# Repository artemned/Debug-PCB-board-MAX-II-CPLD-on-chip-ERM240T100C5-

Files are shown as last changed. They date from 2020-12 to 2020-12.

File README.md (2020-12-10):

# Debug-PCB-board-MAX-II-CPLD-on-chip-ERM240T100C5-
##  Some variation board models   
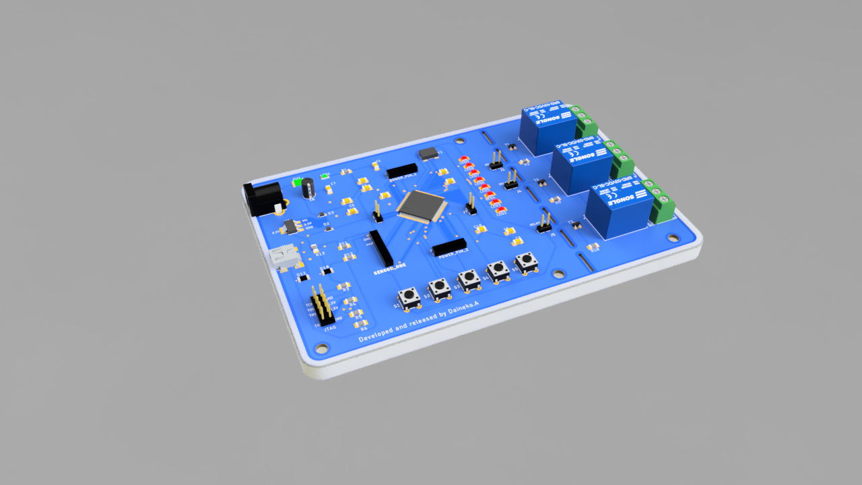
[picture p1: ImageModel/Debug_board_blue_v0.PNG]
 
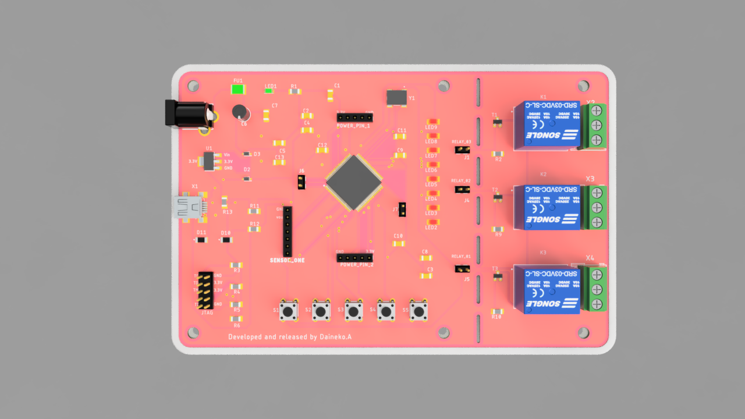
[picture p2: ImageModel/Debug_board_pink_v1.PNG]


### To create this project I was inspired by the ability to synthesize digital circuits using the Verilog and System Verilog languages.From my own experience, I would like to note that many industrial controllers or programmable relays use “Functional block diagram” semantics as a description of control system algorithms. Naturally, the experience gained with this board can be easily used in industry to obtain reliable, efficient and inexpensive solutions.But and not only in industry.Further in this repository in the Examples package, examples of synthesized circuits will appear. The whole project: entirely built on enthusiasm. Therefore, you can become a co-author and contribute.I am grateful to everyone who has read this far. For questions and suggestions, write to the email address: daineko.a32@mail.ru P.S. All goodness and fresh cookies!

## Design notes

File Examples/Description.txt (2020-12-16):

This is the first synthesis for
of this board, so I created a simple circuit that,
when the button is pressed, toggles the next bit of the LED.

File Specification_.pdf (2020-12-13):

Part | Value | Package | Description
C1 | 0.01uF | C1206 | Capacitor
C2 | 1uF | C1206 | Capacitor
C3 | 0.1uF | C1206 | Capacitor
C4 | 1uF | C1206 | Capacitor
C5 | 1uF | C1206 | Capacitor
C6 | 10uF | E2-5 | Polarized capacitor
C7 | 0.1uF | C1206 | Capacitor
C8 | 0.1uF | C1206 | Capacitor
C9 | 0.1uF | C1206 | Capacitor
C10 | 0.1uF | C1206 | Capacitor
C11 | 0.1uF | C1206 | Capacitor
C12 | 0.1uF | C1206 | Capacitor
C13 | 1uF | C1206 | Capacitor
D2 | BAT60AE6327HTSA1 | SOD2513X110N | BAT60AE6327HTSA1 - RECTIFIER, SCHOTTKY, 3A, 10V, SOD-323
D3 | BAT60AE6327HTSA1 | SOD2513X110N | BAT60AE6327HTSA1 - RECTIFIER, SCHOTTKY, 3A, 10V, SOD-323
D10 | 3.6V | BZV55C3V9TP
D11 | 3.3V | BZV55C3V9TP
FU1 | MF-MSMF110_16-2 | FUSC4632X85N | Fuse, PTC, Resettable, SMD,1812,1.1A,16V
IC2 | EPM240T100C5N | QFP50P1600X1600X120-100N | CPLD Max II EPM240T100C5N, TQFP100 EPM240T100C5N
J1 | | 1X02_LOCK | Standard 2-pin 0.1 header. Use with"
J2 | POWER_JACK | POWER_JACK_PTH | Power Jack Connector
J4 | | 1X02_LOCK | Standard 2-pin 0.1 header.
J5 | | 1X02_LOCK | Standard 2-pin 0.1 header.
J6 | | 1X02_LOCK | Standard 2-pin 0.1 header.
J7 | | 1X02_LOCK | Standard 2-pin 0.1 header.
JTAG | | 2X5_NOSILK | Header 5x2
K1 | SRD-05VDC-SL-C | RELAY_SRD-05VDC-SL-C | 5V Trigger Relay Module For Arduino And Raspberry Pi
K2 | SRD-05VDC-SL-C | RELAY_SRD-05VDC-SL-C | 5V Trigger Relay Module For Arduino And Raspberry Pi
K3 | SRD-05VDC-SL-C | RELAY_SRD-05VDC-SL-C | 5V Trigger Relay Module For Arduino And Raspberry
LED1 | | SML0805 | LED
LED2 | | 1206 | LED
LED3 | | 1206 | LED
LED4 | | 1206 | LED
LED5 | | 1206 | LED
LED6 | | 1206 | LED
LED7 | | 1206 | LED
LED8 | | 1206 | LED
LED9 | | 1206 | LED
POWER_PIN_1 | | 1X05_LOCK | Header 5
POWER_PIN_2 | | 1X05_LOCK | Header 5
R1 | 100 | R1206 | Resistor
R2 | 1k | R1206 | Resistor
R3 | 2k | R1206 | Resistor
R4 | 2k | R1206 | Resistor
R5 | 2k | R1206 | Resistor
R6 | 2k | R1206 | Resistor
R9 | 1k | R1206 | Resistor
R10 | 1k | R1206 | Resistor
R11 | 70 | R1206 | Resistor
R12 | 70 | R1206 | Resistor
R13 | 1.5k | R1206 | Resistor
S1 | | TACTILE-PTH | Momentary Switch
S2 | | TACTILE-PTH | Momentary Switch
S3 | | TACTILE-PTH | Momentary Switch
S4 | | TACTILE-PTH | Momentary Switch
S5 | | TACTILE-PTH | Momentary Switch
SENSOR_ONE | | 1X07 | Multi connection point.
T1 | BSS123 | SOT23 | N-CHANNEL MOS FET
T2 | BSS123 | SOT23 | N-CHANNEL MOS FET
T3 | BSS123 | SOT23 | N-CHANNEL MOS FET
U1 | | SOT223 | Voltage Regulator LM1117
X1 | MINI-USB-32005 | 32005-201 | MINI USB-B Conector
X2 | | AK300/3 | Connector
X3 | | AK300/3 | Connector
X4 | | AK300/3 | Connector
Y1 | 100MHz | Crystal Oscillator DSO751SV | Surface Mount Clock Oscilators.

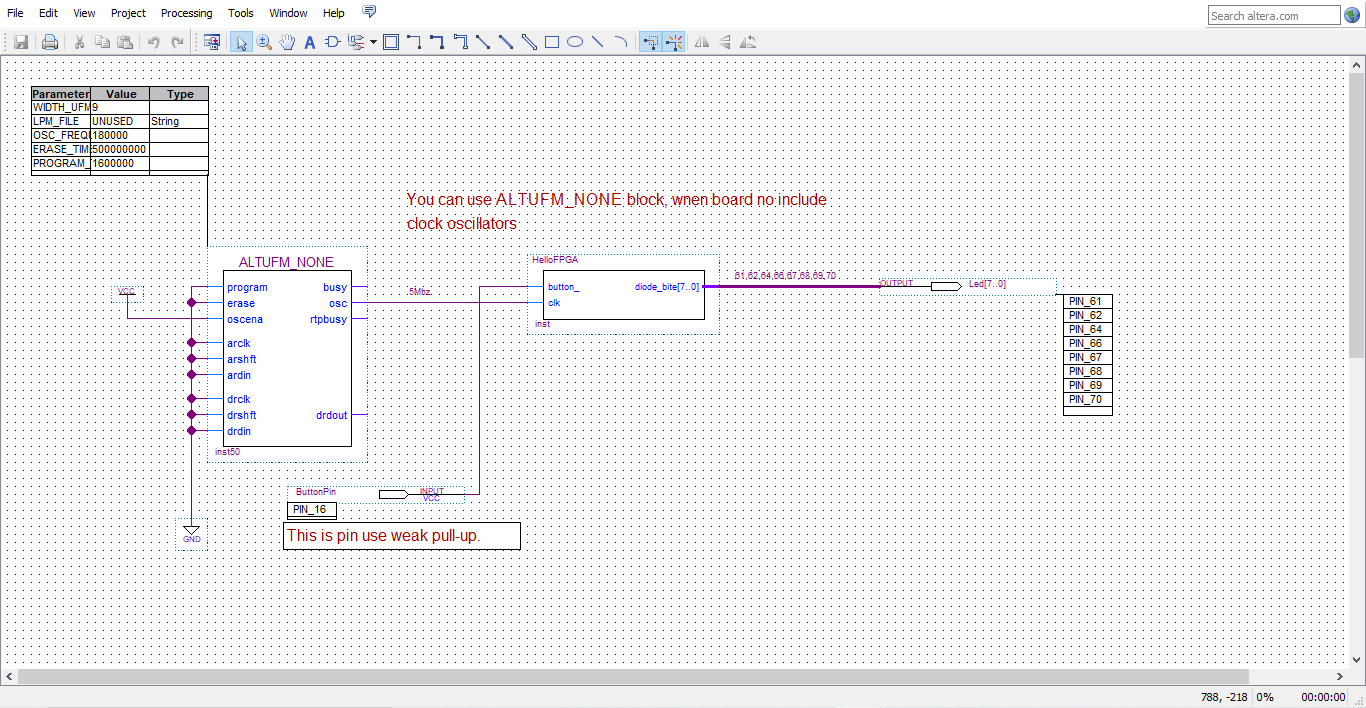
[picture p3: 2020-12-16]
Examples/Base_block..png

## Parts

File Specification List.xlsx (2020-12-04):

Position names | Components name | Quantity | Body
IC2 | ERM240T100C5 | 1
D10,D11 | Silicon Zener diodes BZV55-C3V6 /-C3V3 | 2
U1 | Voltage regulator LM1117 | 1
J2 | PowerJack DC 2.5x5.5 мм | 1
X1 | USB 2.0 mini USB | 1
T1,T2,T3 | Transistors N-chanel IRLML2803 / BSS138 | 3 | SOT23
FU1 | Polyfuse MF-MSMF | 1
LED 1 | Led indication on/off TO-3216BC-PG | 1 | 1206
Y1 | Crystal Oscillator 100MHz DSO751SV | 1
D2,D3 | Schottky Diode BAT60AE6327HTSA1 | 2 | SOD-323
C1,C3,C8-C12 | Capacitors 0.1 мкФ X7R 50В | 7 | smd 1206
C2,C4,C13,C5,C7 | Capacitors 0.1 мкФ X7R 50В | 5 | smd 1206
C6 | Capacitor electrolytic. 10uf 16V | 1
R1 | Resistor 100 | 1 | smd 1206
R3,R4,R5,R6 | Resistors 2kOhm | 4 | smd 1206
R11,R12 | Resistos 75 | 2 | smd 1206
R13 | Resistor 1,5kOhm | 1 | smd 1206
R2,R9,R10 | Resistors 1kOhm | 3 | smd 1206
D0-D7 | Led diodes | 8 | smd 1206
S1-S5 | Button clock KLS7-TS6601-5.0-180 | 5
Power_PIN_1/2 | PCB receptacle 2.54 mm | 2
J1,J4,J5,J6,J7 | PCB pin header | 5
JTAG | Socket IDC-10MS (BH-10) | 1
Sensor_one | PCB receptacle 2.54 mm | 1
K1,K2,K3 | Relays SRD-05VDC-SL-C | 3
X2,X3,X4 | Screw terminal blocks 5mm/3way | 3

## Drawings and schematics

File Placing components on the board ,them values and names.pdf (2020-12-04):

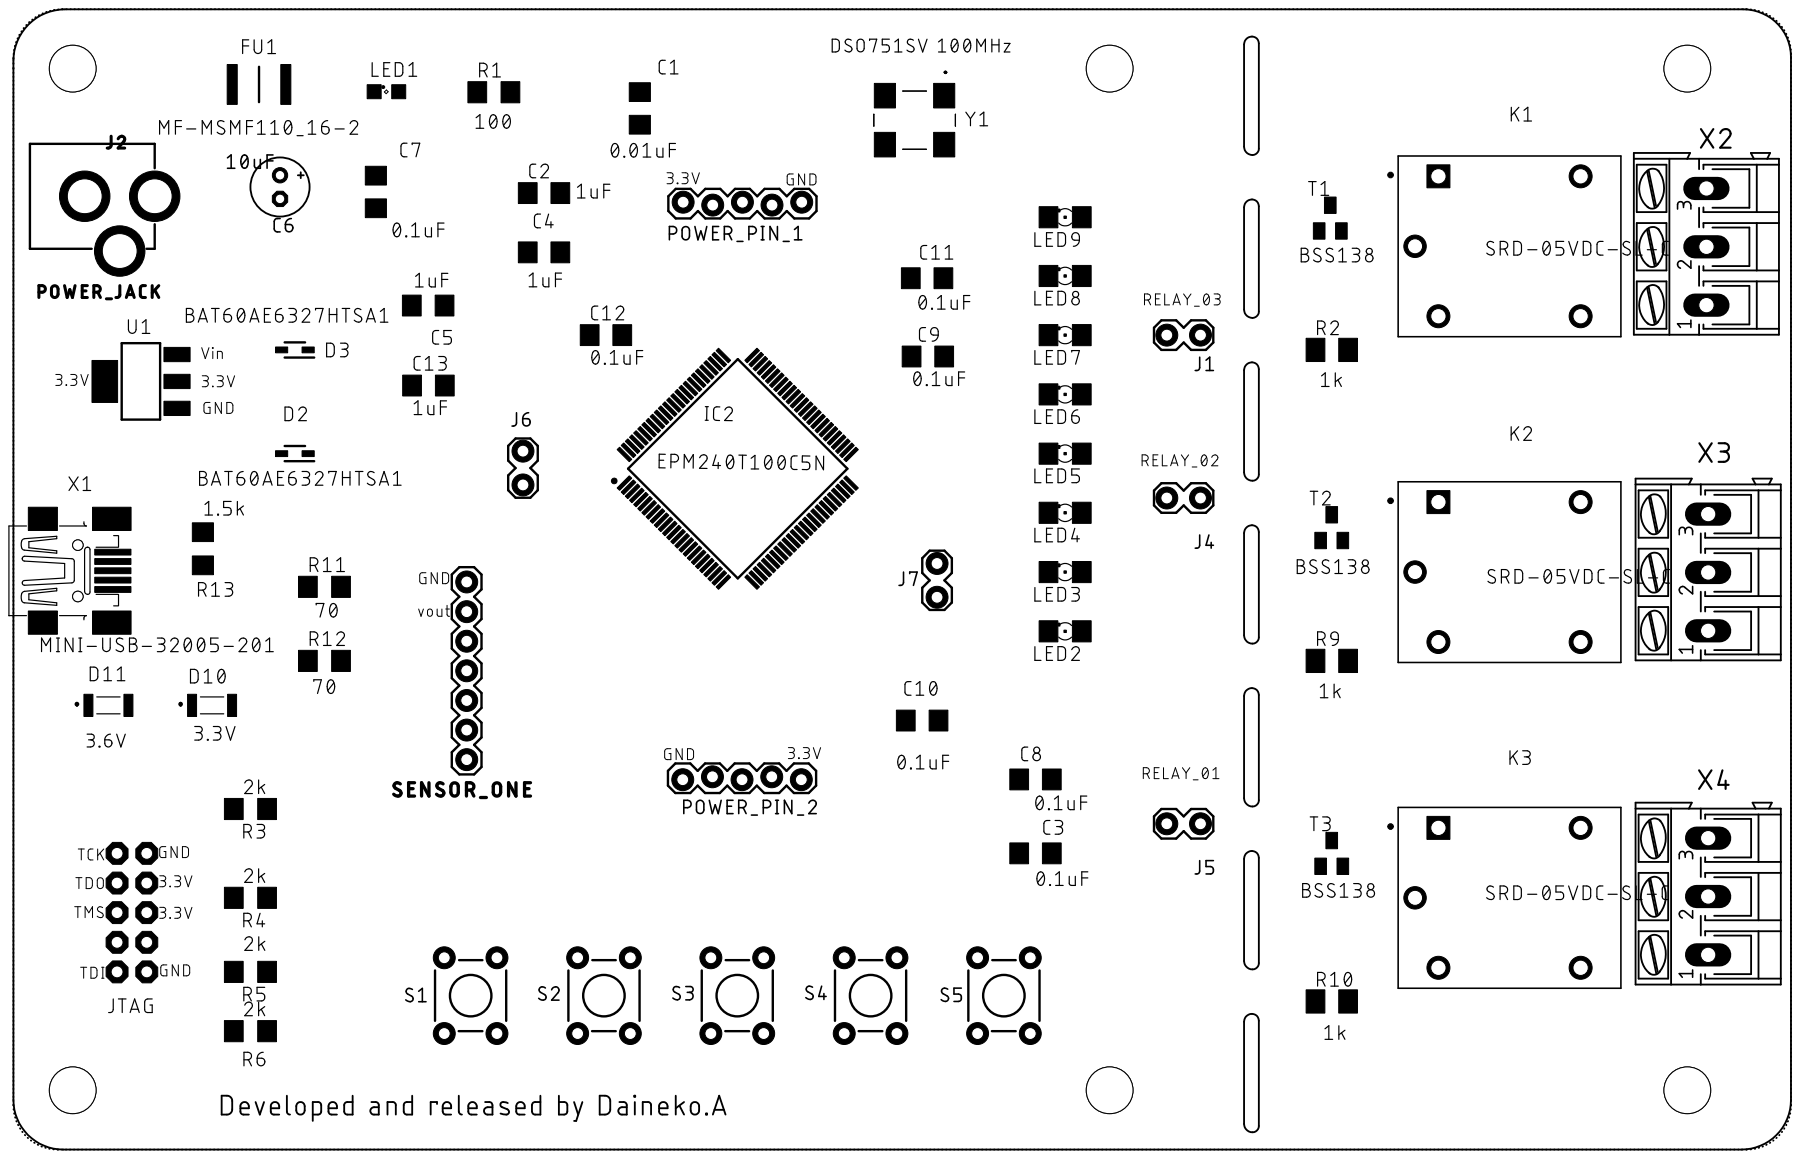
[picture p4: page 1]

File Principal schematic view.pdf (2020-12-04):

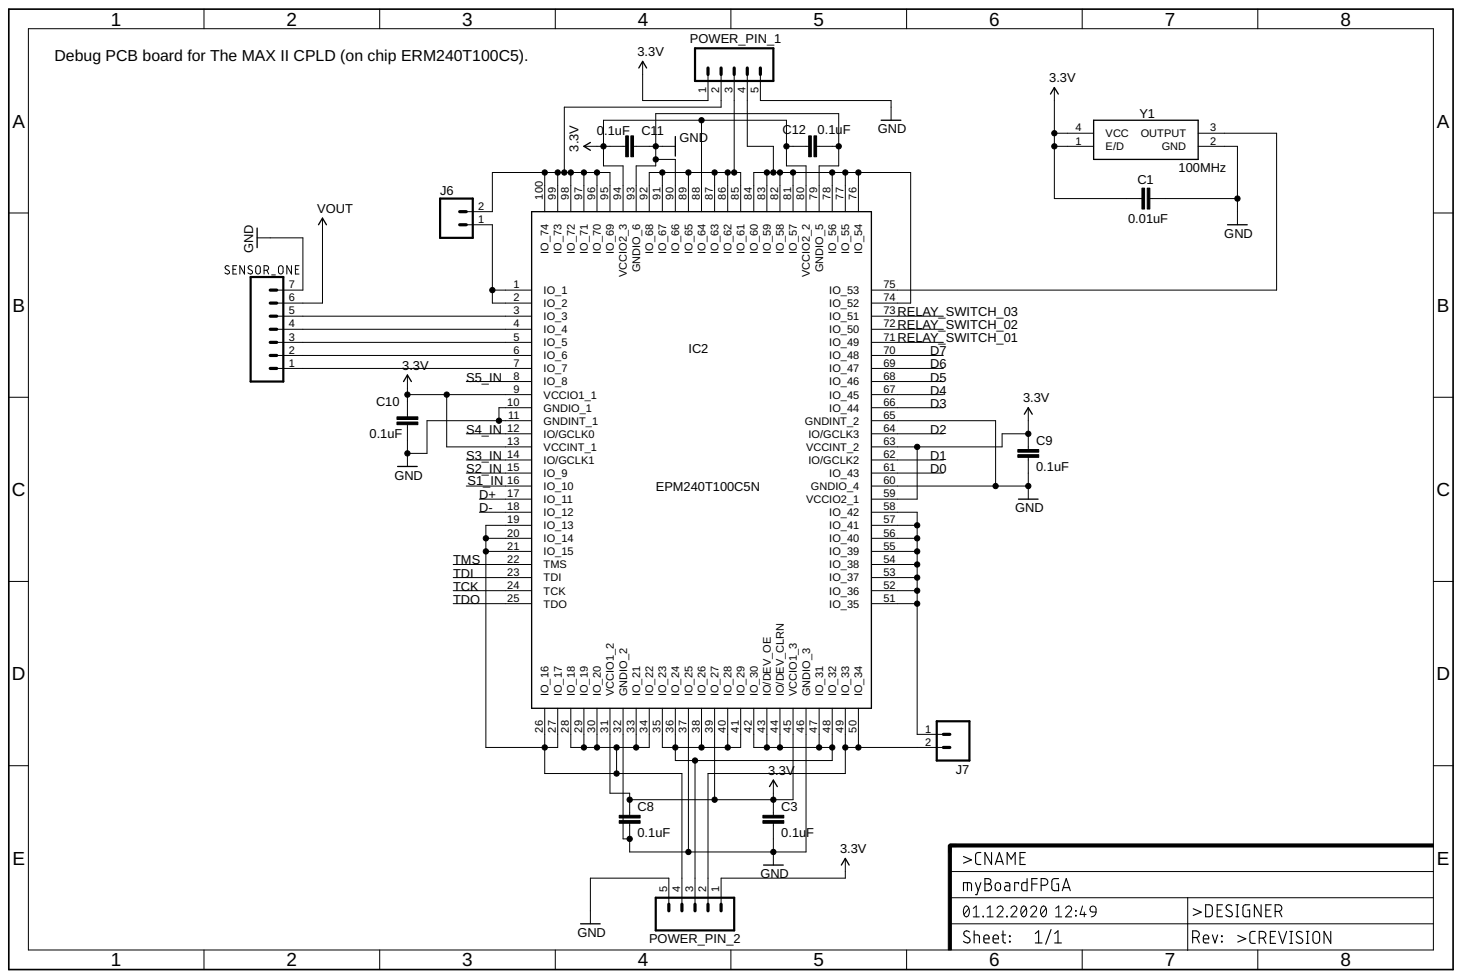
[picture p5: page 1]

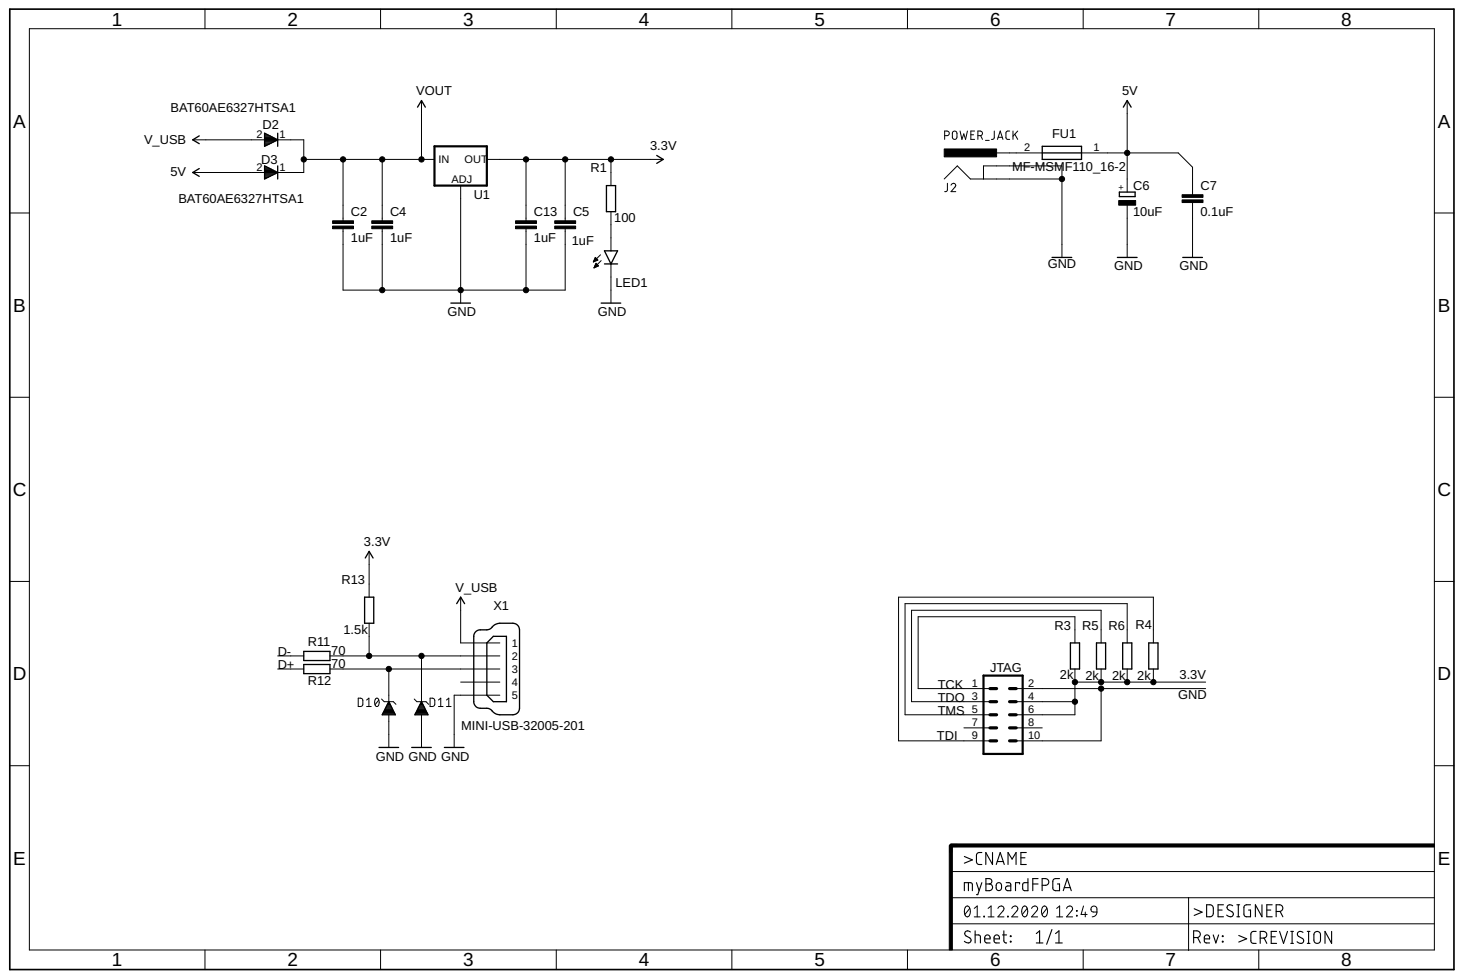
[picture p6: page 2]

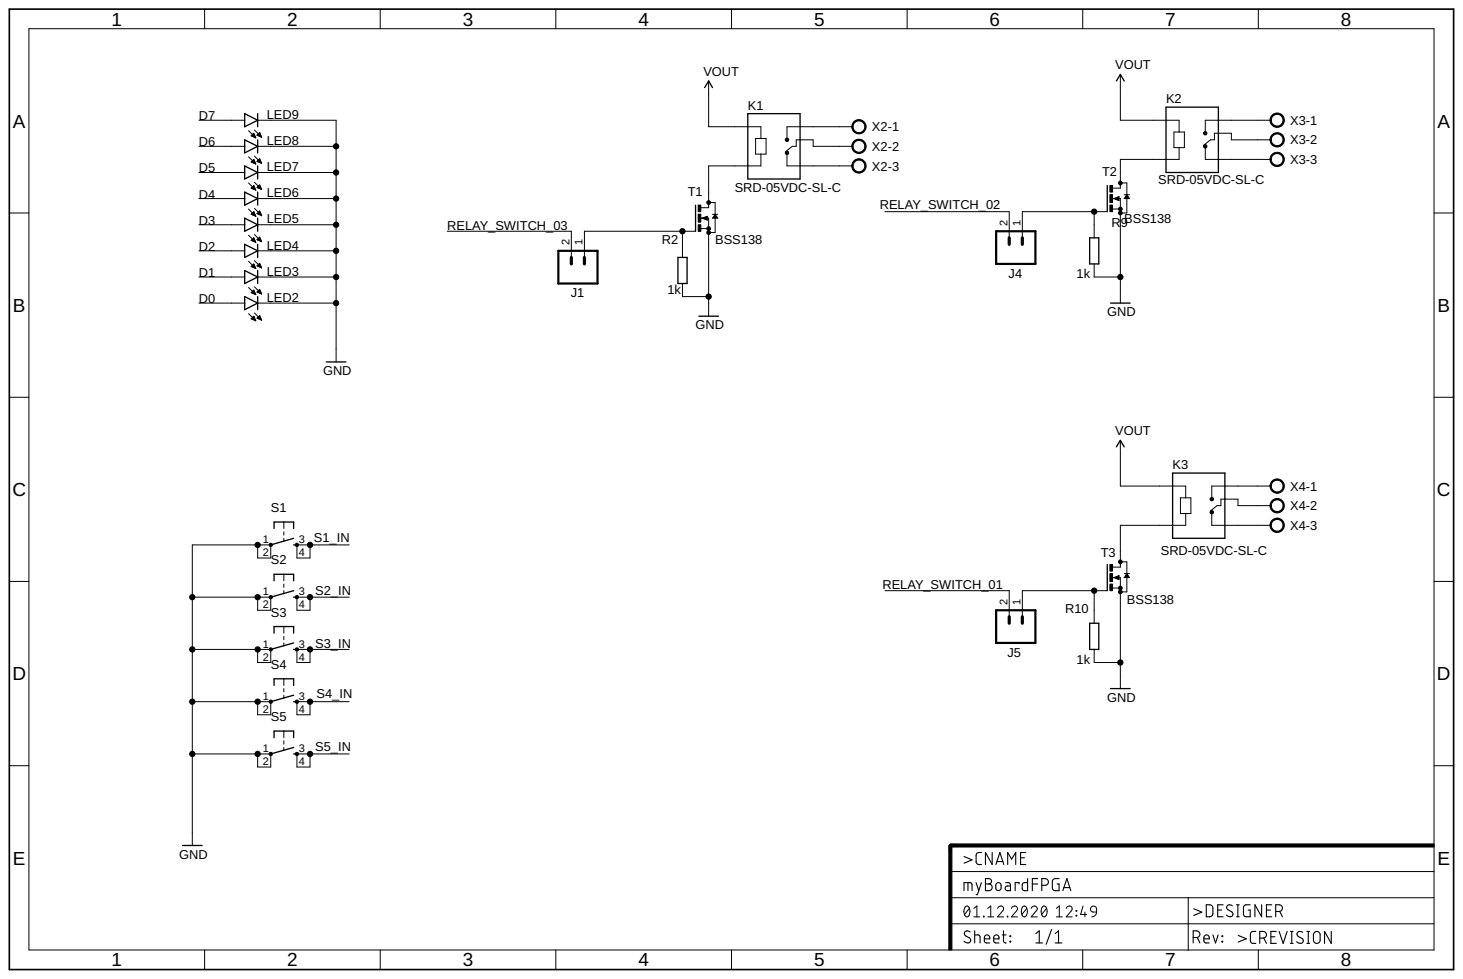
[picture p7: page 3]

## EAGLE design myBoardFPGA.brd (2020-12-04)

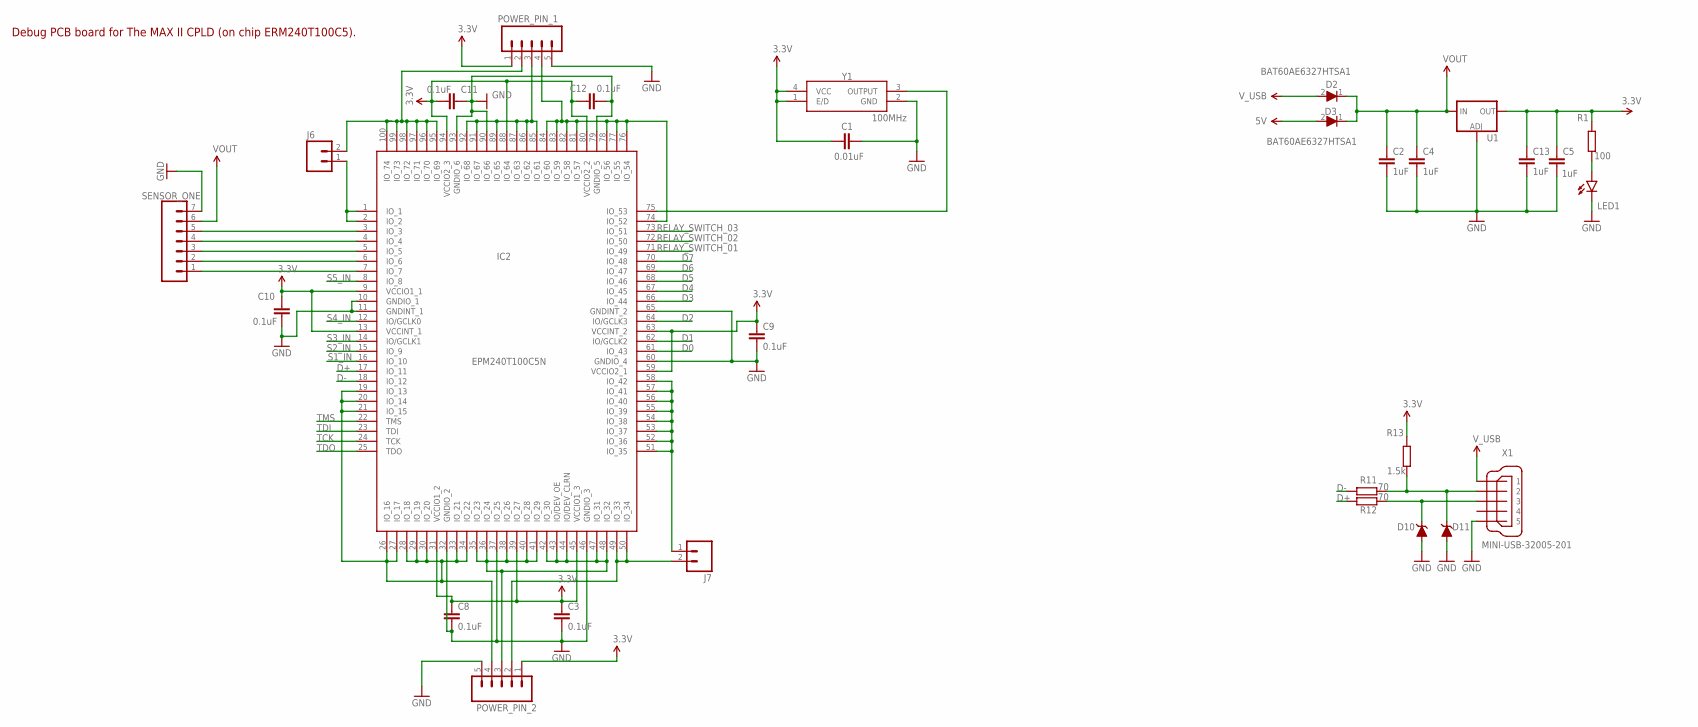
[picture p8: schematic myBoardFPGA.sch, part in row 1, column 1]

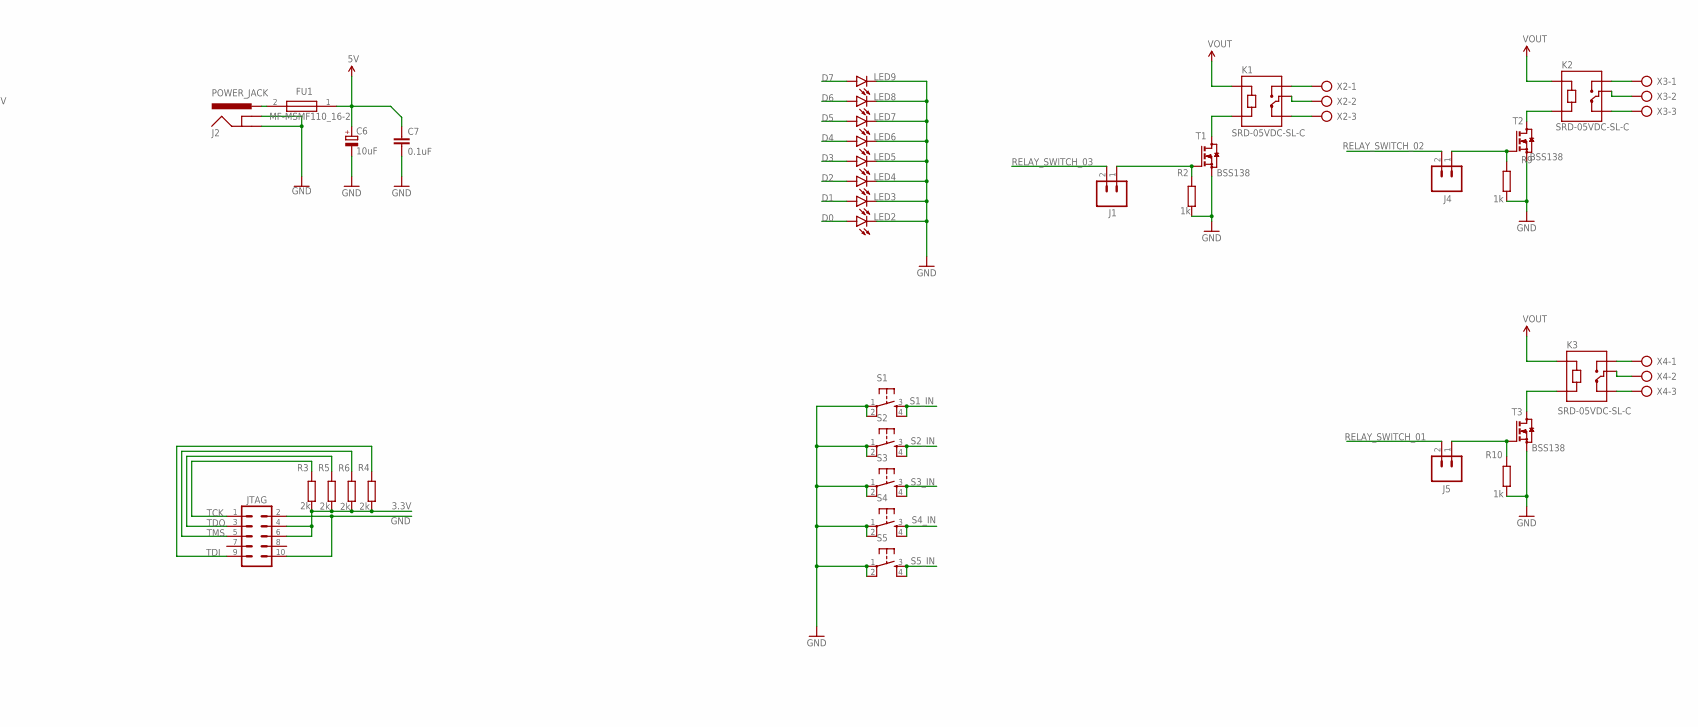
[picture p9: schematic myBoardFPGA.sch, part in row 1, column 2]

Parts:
C1: 0.01uF; C1206
C2, C4, C5, C13: 1uF; C1206
C3, C7, C8, C9, C10, C11, C12: 0.1uF; C1206
C6: 10uF; E2-5
D2, D3: BAT60AE6327HTSA1; SOD2513X110N
D10: 3.3V; BZV55C3V9TP
D11: 3.6; BZV55C3V9TP
FU1: MF-MSMF110_16-2; FUSC4632X85N
IC2: EPM240T100C5N; QFP50P1600X1600X120-100N
J1, J4, J5, J6, J7: M02LOCK; 1X02_LOCK
J2: POWER_JACK; POWER_JACK_PTH
JTAG: M05X2NO_SILK; 2X5_NOSILK
K1, K2, K3: SRD-05VDC-SL-C; RELAY_SRD-05VDC-SL-C
LED1: LEDSML0805; SML0805
LED2, LED3, LED4, LED5, LED6, LED7, LED8, LED9: LEDSMT1206; 1206
POWER_PIN_1, POWER_PIN_2: M05LOCK; 1X05_LOCK
R1: 100; R1206
R2, R9, R10: 1k; R1206
R3, R4, R5, R6: 2k; R1206
R11, R12: 70; R1206
R13: 1.5k; R1206
S1, S2, S3, S4, S5: TAC_SWITCHPTH; TACTILE-PTH
SENSOR_ONE: CONN_07; 1X07
T1, T2, T3: BSS123; SOT23
U1: V_REG_LM1117SOT223; SOT223
X1: MINI-USB-32005-201; 32005-201
X2, X3, X4: AK300/3
Y1: 100MHz; CO4605100000TTR

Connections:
3.3V: C1.1, C3.1, C5.1, C8.1, C9.1, C10.1, C11.2, C12.1, C13.1, IC2.9 (VCCIO1_1), IC2.13 (VCCINT_1), IC2.31 (VCCIO1_2), IC2.39 (IO_27), IC2.45 (VCCIO1_3), IC2.59 (VCCIO2_1), IC2.63 (VCCINT_2), IC2.80 (VCCIO2_2), IC2.88 (IO_64), IC2.94 (VCCIO2_3), JTAG.4, JTAG.6, POWER_PIN_1.1, POWER_PIN_2.1, R1.2, R3.1, R4.1, R5.1, R6.1, R13.2, U1.2 (OUT), U1.4 (OUT), Y1.1 (E/D), Y1.4 (VCC)
5V: C6.+, C7.1, D3.2 (A), FU1.1
D0: IC2.61 (IO_43), LED2.A
D1: IC2.62 (IO/GCLK2), LED3.A
D2: IC2.64 (IO/GCLK3), LED4.A
D3: IC2.66 (IO_44), LED5.A
D4: IC2.67 (IO_45), LED6.A
D5: IC2.68 (IO_46), LED7.A
D6: IC2.69 (IO_47), LED8.A
D7: IC2.70 (IO_48), LED9.A
D+: IC2.17 (IO_11), R12.2
D-: IC2.18 (IO_12), R11.2
GND: C1.2, C2.2, C3.2, C4.2, C5.2, C6.-, C7.2, C8.2, C9.2, C10.2, C11.1, C12.2, C13.2, D10.1 (A), D11.1 (A), IC2.10 (GNDIO_1), IC2.11 (GNDINT_1), IC2.32 (GNDIO_2), IC2.37 (IO_25), IC2.46 (GNDIO_3), IC2.60 (GNDIO_4), IC2.65 (GNDINT_2), IC2.79 (GNDIO_5), IC2.90 (IO_66), IC2.93 (GNDIO_6), J2.GND, J2.GNDBREAK, JTAG.2, JTAG.10, LED1.C, LED2.C, LED3.C, LED4.C, LED5.C, LED6.C, LED7.C, LED8.C, LED9.C, POWER_PIN_1.5, POWER_PIN_2.5, R2.1, R9.1, R10.1, S1.1, S1.2, S2.1, S2.2, S3.1, S3.2, S4.1, S4.2, S5.1, S5.2, SENSOR_ONE.7, T1.2 (S), T2.2 (S), T3.2 (S), U1.1 (ADJ), X1.5, Y1.2 (GND)
unnamed: K1.A2, T1.3 (D)
unnamed: LED1.A, R1.1
unnamed: K1.NO, X2.1
unnamed: K1.NC, X2.3
unnamed: K2.A2, T2.3 (D)
unnamed: J1.1, R2.2, T1.1 (G)
unnamed: K3.A2, T3.3 (D)
unnamed: J4.1, R9.2, T2.1 (G)
unnamed: J5.1, R10.2, T3.1 (G)
unnamed: K1.COM, X2.2
unnamed: K2.NO, X3.1
unnamed: K2.COM, X3.2
unnamed: K2.NC, X3.3
unnamed: K3.COM, X4.2
unnamed: K3.NO, X4.1
unnamed: K3.NC, X4.3
unnamed: IC2.35 (IO_23), IC2.36 (IO_24), IC2.38 (IO_26), IC2.40 (IO_28), IC2.41 (IO_29), IC2.42 (IO_30), IC2.43 (IO/DEV_OE), IC2.44 (IO/DEV_CLRN), IC2.47 (IO_31), IC2.48 (IO_32), POWER_PIN_2.3
unnamed: IC2.19 (IO_13), IC2.20 (IO_14), IC2.21 (IO_15), IC2.26 (IO_16), IC2.27 (IO_17), IC2.28 (IO_18), IC2.29 (IO_19), IC2.30 (IO_20), IC2.33 (IO_21), IC2.34 (IO_22), POWER_PIN_2.4
unnamed: D11.2 (C), R11.1, R13.1, X1.2
unnamed: D10.2 (C), R12.1, X1.3
unnamed: IC2.7 (IO_7), SENSOR_ONE.1
unnamed: IC2.49 (IO_33), IC2.50 (IO_34), J7.2, POWER_PIN_2.2
unnamed: IC2.6 (IO_6), SENSOR_ONE.2
unnamed: IC2.5 (IO_5), SENSOR_ONE.3
unnamed: IC2.51 (IO_35), IC2.52 (IO_36), IC2.53 (IO_37), IC2.54 (IO_38), IC2.55 (IO_39), IC2.56 (IO_40), IC2.57 (IO_41), IC2.58 (IO_42), J7.1
unnamed: IC2.75 (IO_53), Y1.3 (OUTPUT)
unnamed: IC2.4 (IO_4), SENSOR_ONE.4
unnamed: IC2.3 (IO_3), SENSOR_ONE.5
unnamed: IC2.1 (IO_1), IC2.2 (IO_2), J6.1
unnamed: IC2.95 (IO_69), IC2.96 (IO_70), IC2.97 (IO_71), IC2.98 (IO_72), IC2.99 (IO_73), IC2.100 (IO_74), J6.2, POWER_PIN_1.2
unnamed: FU1.2, J2.PWR
unnamed: IC2.74 (IO_52), IC2.76 (IO_54), IC2.77 (IO_55), IC2.78 (IO_56), IC2.81 (IO_57), IC2.82 (IO_58), IC2.83 (IO_59), IC2.84 (IO_60), POWER_PIN_1.4
unnamed: IC2.85 (IO_61), IC2.86 (IO_62), IC2.87 (IO_63), IC2.89 (IO_65), IC2.91 (IO_67), IC2.92 (IO_68), POWER_PIN_1.3
RELAY_SWITCH_01: IC2.71 (IO_49), J5.2
RELAY_SWITCH_02: IC2.72 (IO_50), J4.2
RELAY_SWITCH_03: IC2.73 (IO_51), J1.2
S1_IN: IC2.16 (IO_10), S1.3, S1.4
S2_IN: IC2.15 (IO_9), S2.3, S2.4
S3_IN: IC2.14 (IO/GCLK1), S3.3, S3.4
S4_IN: IC2.12 (IO/GCLK0), S4.3, S4.4
S5_IN: IC2.8 (IO_8), S5.3, S5.4
TCK: IC2.24 (TCK), JTAG.1, R3.2
TDI: IC2.23 (TDI), JTAG.9, R4.2
TDO: IC2.25 (TDO), JTAG.3, R5.2
TMS: IC2.22 (TMS), JTAG.5, R6.2
VOUT: C2.1, C4.1, D2.1 (K), D3.1 (K), K1.A1, K2.A1, K3.A1, SENSOR_ONE.6, U1.3 (IN)
V_USB: D2.2 (A), X1.1

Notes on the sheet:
Debug PCB board for The MAX II CPLD (on chip ERM240T100C5).

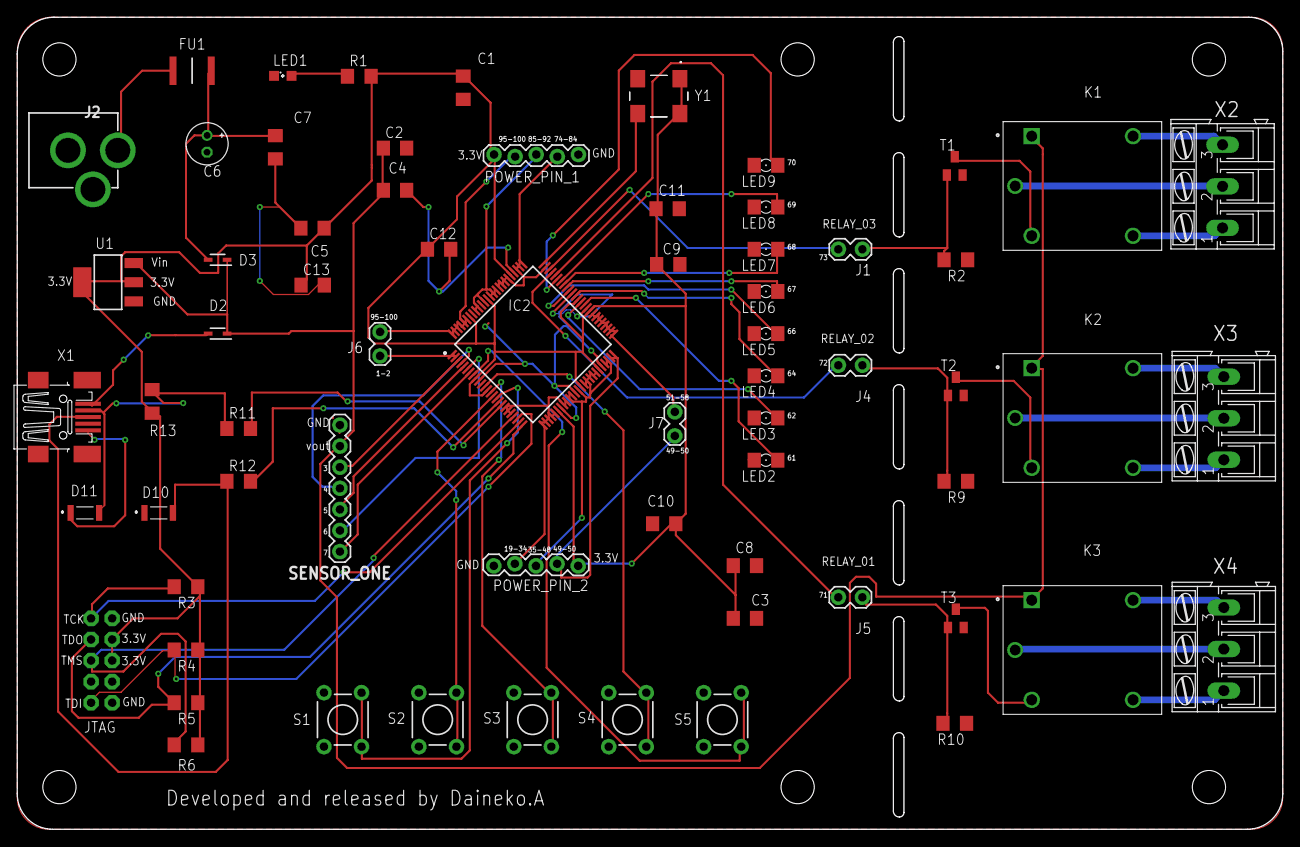
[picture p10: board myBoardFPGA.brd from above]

Board: 2 copper layers, 152.4 x 97.8 mm, 66 parts (0 on the bottom side), 60 nets.

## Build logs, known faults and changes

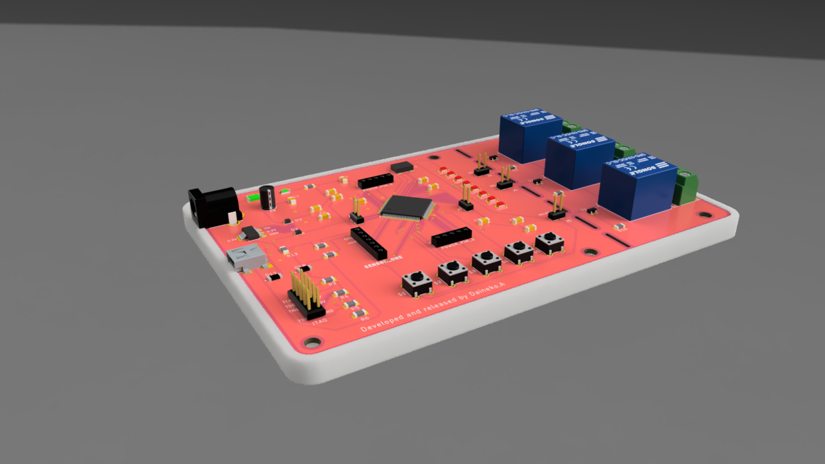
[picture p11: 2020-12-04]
ImageModel/Debug_board_pink_v0.PNG

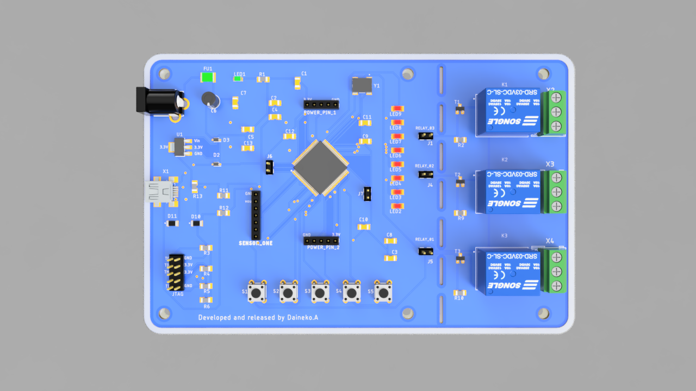
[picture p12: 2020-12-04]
ImageModel/Debug_board_blue_v1.PNG

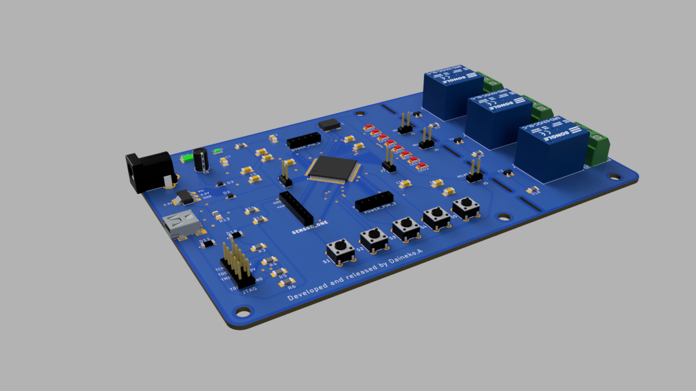
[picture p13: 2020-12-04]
ImageModel/Debug_board_blue_v2.png

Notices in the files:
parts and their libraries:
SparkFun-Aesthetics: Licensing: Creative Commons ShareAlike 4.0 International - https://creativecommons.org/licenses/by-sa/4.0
